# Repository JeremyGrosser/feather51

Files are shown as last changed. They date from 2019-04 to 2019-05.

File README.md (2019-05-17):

# FEATHER51

**This project is a work in progress**

FEATHER51 is an [Adafruit Feather](https://learn.adafruit.com/adafruit-feather/feather-specification) compatible main-board using the Silicon Labs EFM8UB1 microcontroller. It is designed to be an easy entry point for learning assembly language on real hardware using an open source toolchain. This project is Open Source Hardware! See [LICENSE](LICENSE) for details.

**Arduino for people that want to learn Assembly**

# Project status

Ten revision A boards have been manufactured and tested with no known defects. The efm8flash utility is being developed as a portable open source flash programming tool for the factory USB bootloader. It has bugs.

A small number of JLink to C2D adapter boards are available for debugging using
the six pin header, though this adapter shouldn't be needed for most
applications.

[Schematic](feather51/feather51.pdf)

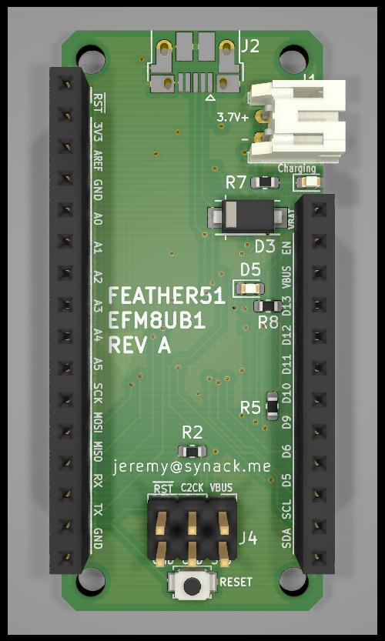
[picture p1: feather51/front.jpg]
Board Front

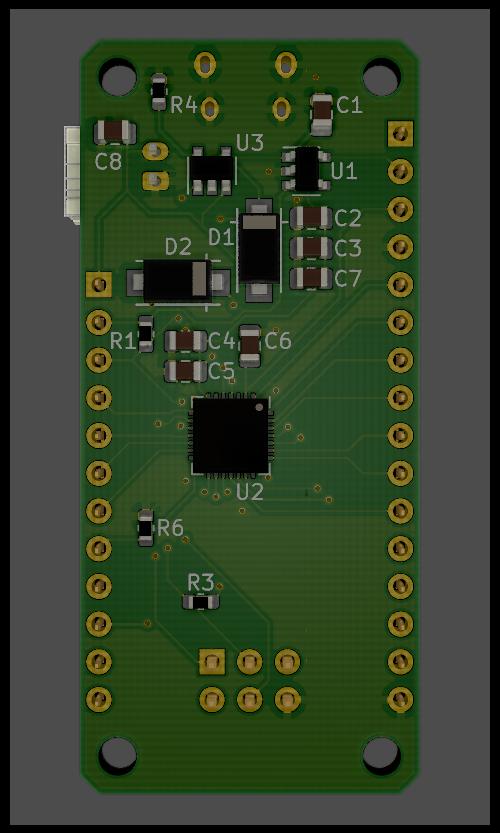
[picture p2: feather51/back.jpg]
Board Back


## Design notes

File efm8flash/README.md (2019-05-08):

efm8flash is a tool for flashing EFM8UB1 microcontrollers over USB using the
factory bootloader.

# Getting started

## Runtime dependencies

- libhidapi-libusb0

## Build dependencies

- C compiler
- make
- pkg-config
- libhidapi-dev

## Building from source

    ./configure
    make
    make install

# Usage

    efm8flash flash.bin

## Converting Intel Hex files to binary

Many 8051 assemblers output Intel Hex format binaries. Use objcopy to convert
them to binary.

    objcopy -I ihex -O binary flash.ihx flash.bin

## hex2boot

The hex2boot step shown in the EFM8 documentation is not necessary when using
efm8flash.

## Forcing the device into bootloader mode

If the first byte of flash is not 0xFF upon power on, the EFM8UB1 will execute
user code rather than jumping to the bootloader. To force the device into
bootloader mode in this situation, attach a jumper between C2D and GND, then
press the reset button while the USB cable is connected.

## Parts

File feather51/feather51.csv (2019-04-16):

Reference | Value | Footprint | Datasheet
C4 | 4.7uF | Capacitor_SMD:C_0805_2012Metric | ~
C5 | 0.1uF | Capacitor_SMD:C_0805_2012Metric | ~
R3 | 1k | Resistor_SMD:R_0603_1608Metric | ~
J2 | USB_B_Micro | Connector_USB:USB_Micro-B_Amphenol_10103594-0001LF_Horizontal | ~
J3 | Conn_01x12 | Connector_PinSocket_2.54mm:PinSocket_1x12_P2.54mm_Vertical | ~
J5 | Conn_01x16 | Connector_PinSocket_2.54mm:PinSocket_1x16_P2.54mm_Vertical | ~
D1 | 1N5817 | synack-common:DO-214AC | http://www.vishay.com/docs/88525/1n5817.pdf
C1 | 10uF | Capacitor_SMD:C_0805_2012Metric | ~
R1 | 100k | Resistor_SMD:R_0603_1608Metric | ~
U1 | SPX3819M5-L-3-3 | Package_TO_SOT_SMD:SOT-23-5 | https://www.exar.com/content/document.ashx?id=22106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
C2 | 10uF | Capacitor_SMD:C_0805_2012Metric | ~
C3 | 1uF | Capacitor_SMD:C_0805_2012Metric | ~
J1 | BATTERY | Connector_JST:JST_PH_S2B-PH-K_1x02_P2.00mm_Horizontal | ~
C6 | 1uF | Capacitor_SMD:C_0805_2012Metric | ~
C7 | 10uF | Capacitor_SMD:C_0805_2012Metric | ~
SW1 | RESET | Button_Switch_SMD:SW_SPST_B3U-1000P
D4 | ORANGE | LED_SMD:LED_0603_1608Metric | ~
U3 | MCP73831-2-OT | Package_TO_SOT_SMD:SOT-23-5 | http://ww1.microchip.com/downloads/en/DeviceDoc/20001984g.pdf
R7 | 1k | Resistor_SMD:R_0603_1608Metric | ~
R4 | 100k | Resistor_SMD:R_0603_1608Metric | ~
C8 | 10uF | Capacitor_SMD:C_0805_2012Metric | ~
R5 | 100k | Resistor_SMD:R_0603_1608Metric | ~
R6 | 100k | Resistor_SMD:R_0603_1608Metric | ~
D5 | RED | LED_SMD:LED_0603_1608Metric | ~
R8 | 2.2k | Resistor_SMD:R_0603_1608Metric | ~
R2 | 1k | Resistor_SMD:R_0603_1608Metric | ~
D2 | 1N5817 | synack-common:DO-214AC | http://www.vishay.com/docs/88525/1n5817.pdf
D3 | 1N5817 | synack-common:DO-214AC | http://www.vishay.com/docs/88525/1n5817.pdf
U2 | EFM8UB10F16G-C-QFN28 | Package_DFN_QFN:QFN-28-1EP_5x5mm_P0.5mm_EP3.35x3.35mm
J4 | C2D | Connector_PinHeader_2.54mm:PinHeader_2x03_P2.54mm_Vertical | ~

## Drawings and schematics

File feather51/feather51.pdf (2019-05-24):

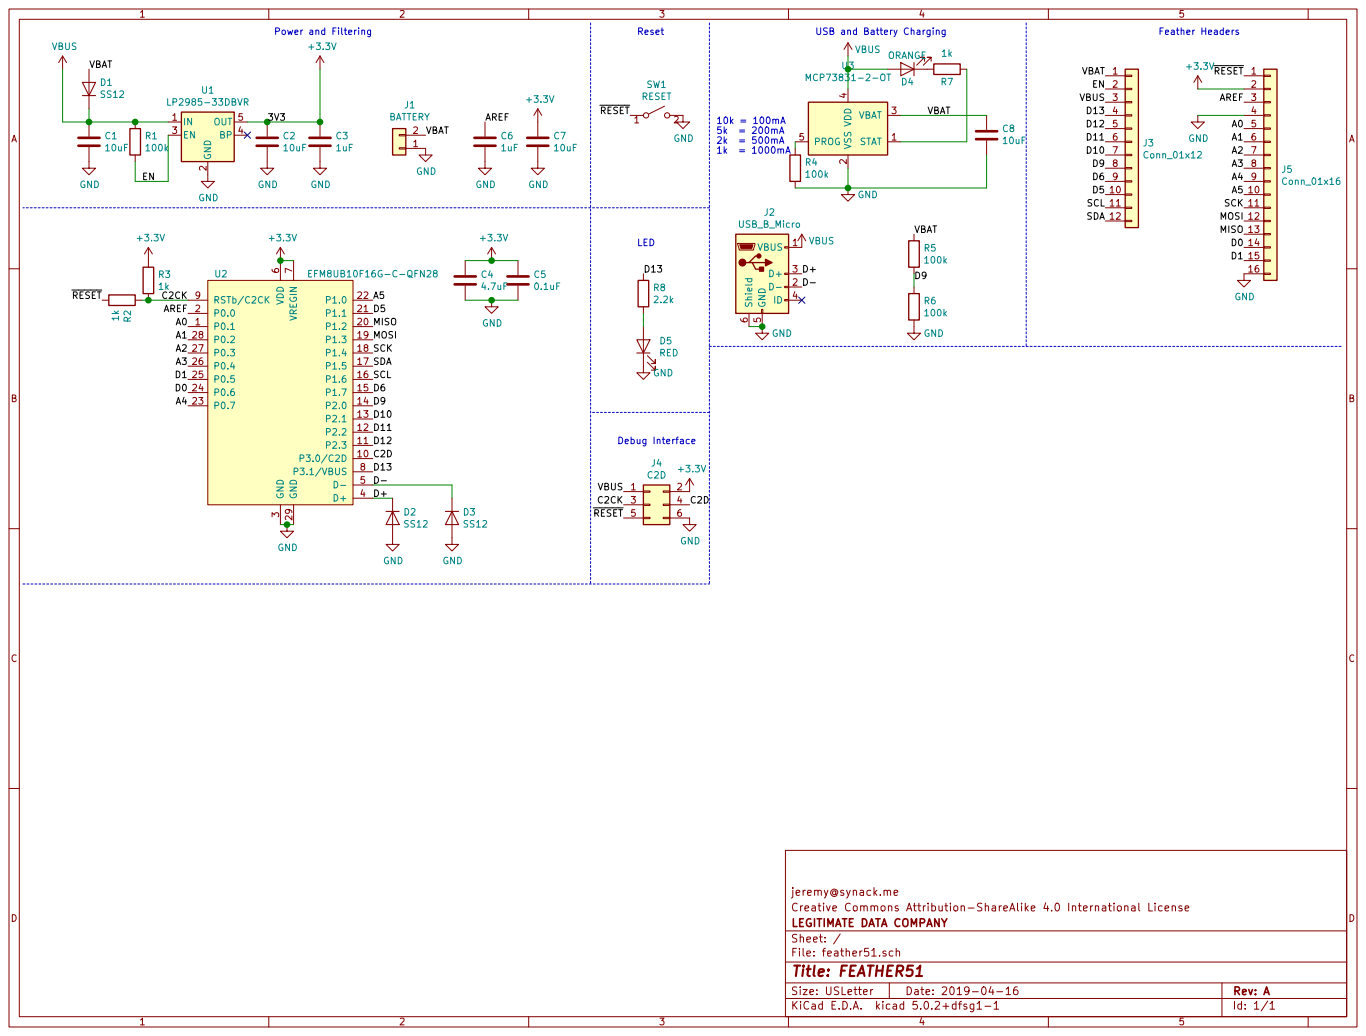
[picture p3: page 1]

7 P3.1/VBUS 8 RSTb/C2CK 9 U2 EFM8UB10F16G-C-QFN28 D13 D12 D11 D10 D9 D6 AREF D5 GND

jeremy@synack.me
File: feather51.sch Sheet: / LEGITIMATE DATA COMPANY Creative Commons Attribution-ShareAlike 4.0 International License

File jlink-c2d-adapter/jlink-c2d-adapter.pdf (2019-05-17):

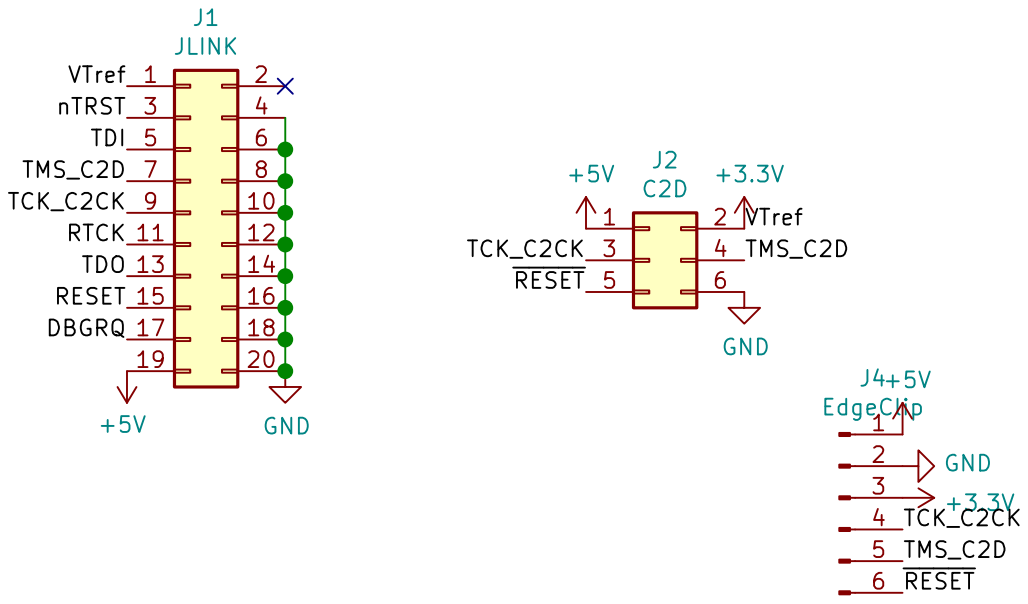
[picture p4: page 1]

File: jlink-c2d-adapter.sch Sheet: /
Id: 1/1 Title:

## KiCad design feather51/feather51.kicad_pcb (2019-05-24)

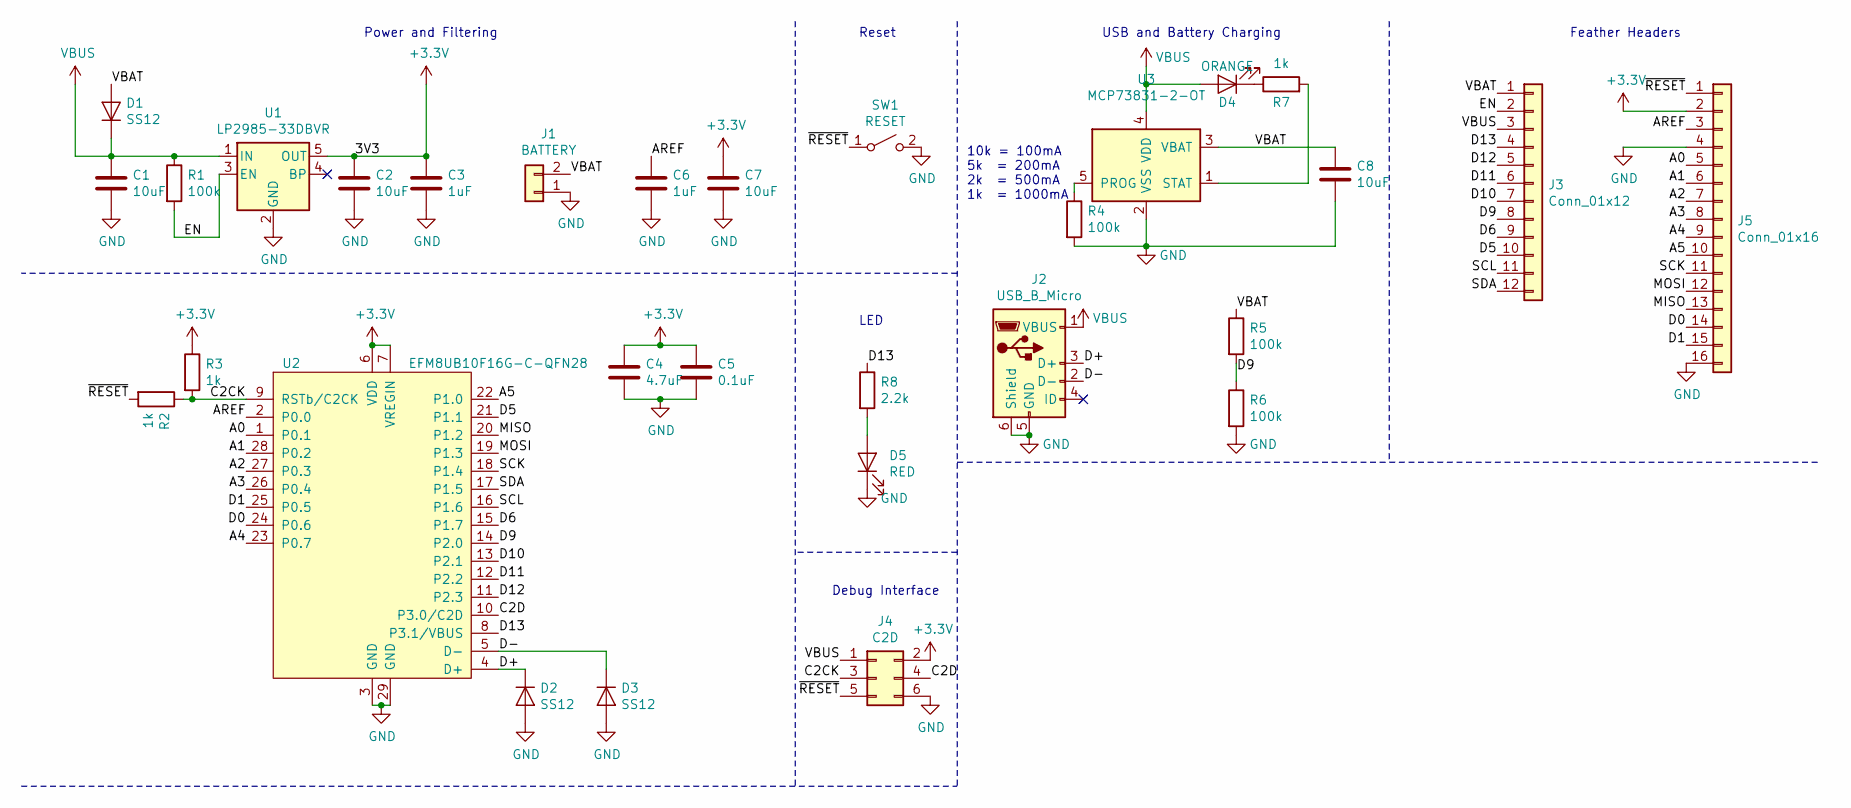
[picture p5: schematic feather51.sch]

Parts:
C1, C2, C7, C8: 10uF; C_0805_2012Metric
C3, C6: 1uF; C_0805_2012Metric
C4: 4.7uF; C_0805_2012Metric
C5: 0.1uF; C_0805_2012Metric
D1, D2, D3: SS12; DO-214AC
D4: ORANGE; LED_0603_1608Metric
D5: RED; LED_0603_1608Metric
J1: BATTERY; JST_PH_S2B-PH-K_1x02_P2.00mm_Horizontal
J2: USB_B_Micro; USB_Micro-B_Amphenol_10103594-0001LF_Horizontal
J3: Conn_01x12; PinSocket_1x12_P2.54mm_Vertical
J4: C2D; PinHeader_2x03_P2.54mm_Vertical
J5: Conn_01x16; PinSocket_1x16_P2.54mm_Vertical
R1, R4, R5, R6: 100k; R_0603_1608Metric
R2, R3, R7: 1k; R_0603_1608Metric
R8: 2.2k; R_0603_1608Metric
SW1: RESET; SW_SPST_B3U-1000P
U1: LP2985-33DBVR; SOT-23-5
U2: EFM8UB10F16G-C-QFN28; QFN-28-1EP_5x5mm_P0.5mm_EP3.35x3.35mm
U3: MCP73831-2-OT; SOT-23-5

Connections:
+3V3: C2.1, C3.1, C4.1, C5.1, C7.1, J4.2, J5.2, R3.1, U1.5 (OUT), U2.6 (VDD), U2.7 (VREGIN)
/A0: J5.5, U2.1 (P0.1)
/A1: J5.6, U2.28 (P0.2)
/A2: J5.7, U2.27 (P0.3)
/A3: J5.8, U2.26 (P0.4)
/A4: J5.9, U2.23 (P0.7)
/A5: J5.10, U2.22 (P1.0)
/AREF: C6.1, J5.3, U2.2 (P0.0)
/C2CK: J4.3, R2.1, R3.2, U2.9 (RSTb/C2CK)
/C2D: J4.4, U2.10 (P3.0/C2D)
/D0: J5.14, U2.24 (P0.6)
/D1: J5.15, U2.25 (P0.5)
/D5: J3.10, U2.21 (P1.1)
/D6: J3.9, U2.15 (P1.7)
/D9: J3.8, R5.2, R6.1, U2.14 (P2.0)
/D10: J3.7, U2.13 (P2.1)
/D11: J3.6, U2.12 (P2.2)
/D12: J3.5, U2.11 (P2.3)
/D13: J3.4, R8.1, U2.8 (P3.1/VBUS)
/D+: D2.1 (K), J2.3 (D+), U2.4 (D+)
/D-: D3.1 (K), J2.2 (D-), U2.5 (D-)
/EN: J3.2, R1.2, U1.3 (EN)
/MISO: J5.13, U2.20 (P1.2)
/MOSI: J5.12, U2.19 (P1.3)
/SCK: J5.11, U2.18 (P1.4)
/SCL: J3.11, U2.16 (P1.6)
/SDA: J3.12, U2.17 (P1.5)
/VBAT: C8.2, D1.2 (A), J1.2, J3.1, R5.1, U3.3 (VBAT)
/~RESET: J4.5, J5.1, R2.2, SW1.1 (A)
GND: C1.2, C2.2, C3.2, C4.2, C5.2, C6.2, C7.2, C8.1, D2.2 (A), D3.2 (A), D5.1 (K), J1.1, J2.5 (GND), J2.6 (Shield), J4.6, J5.4, J5.16, R4.2, R6.2, SW1.2 (B), U1.2 (GND), U2.3 (GND), U2.29 (GND), U3.2 (VSS)
unnamed: D4.1 (K), R7.1
unnamed: D5.2 (A), R8.2
unnamed: R4.1, U3.5 (PROG)
unnamed: R7.2, U3.1 (STAT)
VBUS: C1.1, D1.1 (K), D4.2 (A), J2.1 (VBUS), J3.3, J4.1, R1.1, U1.1 (IN), U3.4 (VDD)

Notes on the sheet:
Feather Headers
Power and Filtering
Reset
10k = 100mA 5k = 200mA 2k = 500mA 1k = 1000mA
USB and Battery Charging
LED
Debug Interface

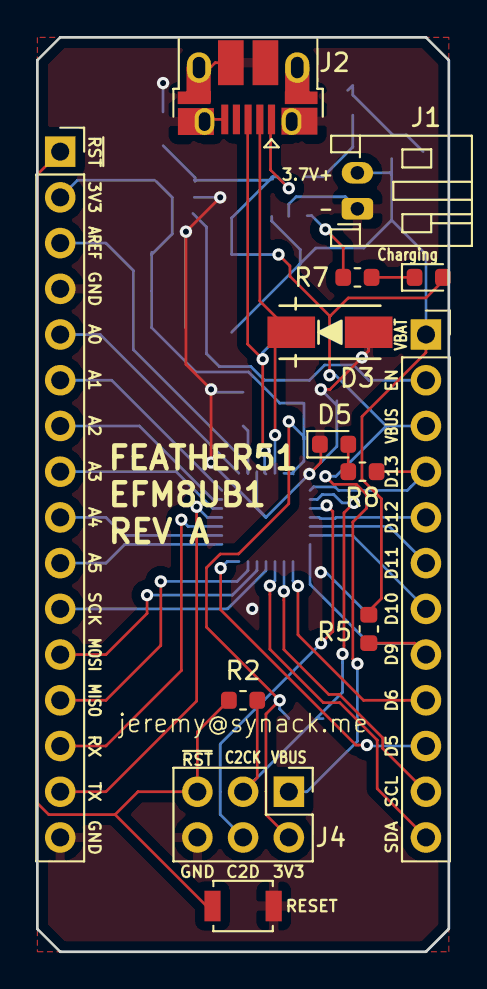
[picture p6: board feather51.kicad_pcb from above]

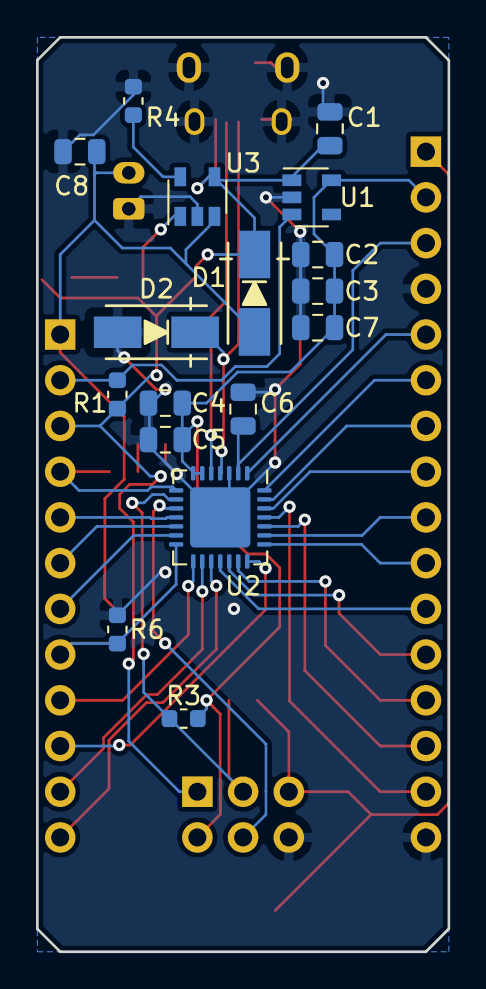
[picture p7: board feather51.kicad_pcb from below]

Board: 2 copper layers, 22.9 x 50.8 mm, 30 parts (17 on the bottom side), 35 nets.

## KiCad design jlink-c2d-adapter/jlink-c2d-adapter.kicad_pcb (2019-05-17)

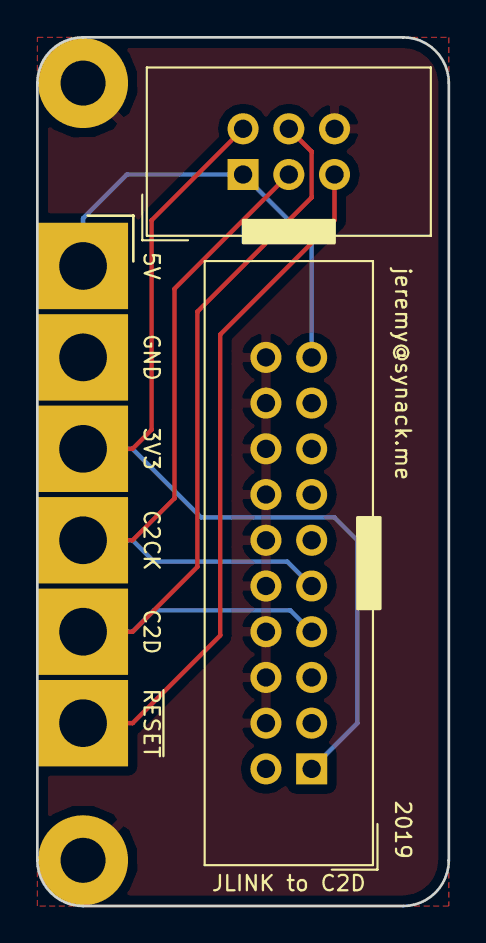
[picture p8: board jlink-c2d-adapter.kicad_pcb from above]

Board: 2 copper layers, 22.9 x 48.3 mm, 3 parts (0 on the bottom side), 6 nets.

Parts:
J1: JLINK; IDC-Header_2x10_P2.54mm_Vertical
J2: C2D; IDC-Header_2x03_P2.54mm_Vertical
J4: EdgeClip; CardEdge6P

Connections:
+3V3: J1.1, J2.2, J4.3
+5V: J1.19, J2.1, J4.1
/TCK_C2CK: J1.9, J2.3, J4.4
/TMS_C2D: J1.7, J2.4, J4.5
/~RESET: J2.5, J4.6
GND: J1.4, J1.6, J1.8, J1.10, J1.12, J1.14, J1.16, J1.18, J1.20, J2.6, J4.2

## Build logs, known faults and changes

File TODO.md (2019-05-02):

Revision A
- User LED should be relocated next to the USB connector
- Add a PTC fuse on VBUS
- Find smaller protection diodes
- Replace reset button with a right angle variant
- Add copper rings for clearance around mounting holes
- Find a 12V tolerant battery charge controller or add a jumper to disable it

Production image
- FORTH interpreter on UART/USB?

Test fixture specification
- Pogo pins connecting to the target board
- 3D printed spacer to align the test fixture, target board, and pogo pins. Use
  the mounting holes.
- A microswitch applies power to the target and begins testing when the pogo
  pins are compressed.
- Each test should light up a green LED on passing, or a red LED upon failure.
  The testing process should halt immediately if any test fails.
- Tests:
    1. Query the target C2 interface for chip revision and serial number
    2. Poke the port SFRs to configure each pin as an output and toggle them individually
    3. Configure all pins as inputs, toggle input values and read pin state
    4. Erase flash, program production image
    5. Issue reset, wait for acknowledgement of MBIST pass on UART
- Write the serial number and test results to nonvolatile storage (microSD card)

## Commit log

2019-04-15 0.7mil spacing is wrong
    [feather51.kicad_pcb]
2019-04-16 Layout locked
    [feather51.kicad_pcb]
2019-04-16 Released to Manufacturing
    [feather51-B.Cu.gbl, feather51-B.Fab.gbr, feather51-B.Mask.gbs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]
2019-04-16 Add revision A schematic PDF
    [feather51.sch]
2019-04-17 Add LICENSE, README, fix PDF rotation
    [feather51.sch]
2019-04-17 Link to schematic from README
2019-04-17 Add board renders
2019-04-17 Note about mounting hole clearance
2019-04-17 Disable internal voltage regulator
2019-04-30 Split device-specific init out, fancier makefile.
2019-05-17 commit test-driver
2019-05-17 efm8flash successfully flashes a program! verification currently disabled
2019-05-17 Add JLink to C2D adapter board, handy for debugging.
    [jlink-c2d-adapter-B.Cu.gbl, jlink-c2d-adapter-B.Mask.gbs, jlink-c2d-adapter-B.Paste.gbp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]
2019-05-17 A note about the jlink-c2d-adapter board in README
2019-05-24 Update diode and LDO part numbers to match as-built revision A boards
    [feather51.kicad_pcb, feather51.sch]
2019-06-01 Motor blink
